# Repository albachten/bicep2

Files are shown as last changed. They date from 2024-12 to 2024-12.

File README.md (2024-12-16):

# Bicep2 - Flexing my "ARM" muscles

This is a simple ARM Cortex M0 development board with:
* SAMD21G18A cpu
* 0.96" OLED I2C display
* LiPo battery
* 2 I2C connectors (1 QWIIC and 1 header)
* 1 extra serial connector
* 1 rotary switch
* 4 pushbuttons
* 4 LEDs
* 1 neopixel LED
* 2 MB SPI flash

This is designed for prototyping.
I find that almost every time I'm trying new hardware I need some combination of LEDs, buttons, rotary switch, or an OLED display.
The display is connected to the I2C bus and can be disconnected by removing the jumper resistors.
The switches and LEDs can be connected to digital pins with jumper wires.

The SPI flash enables using the same bootloader as the adafruit feather m0 express.  This memory is typically used for CircuitPython but can also be used for general storage.

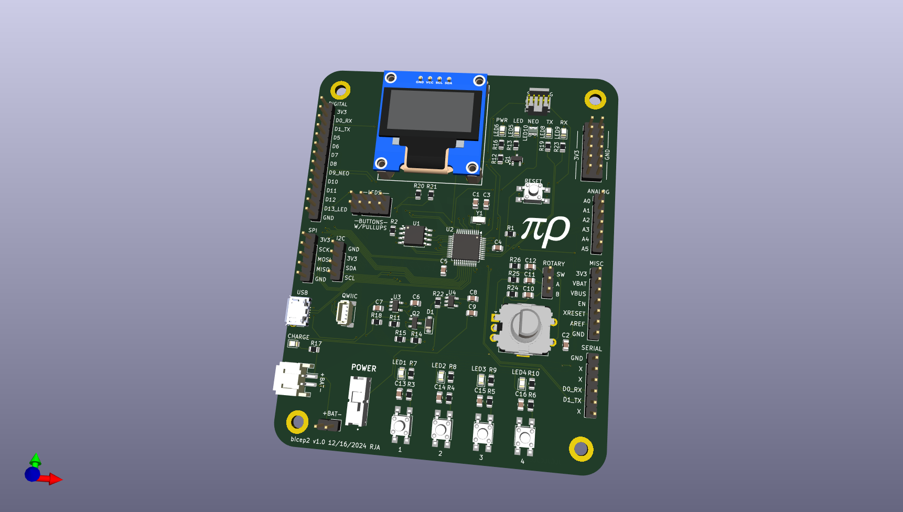
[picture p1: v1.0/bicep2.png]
PCB


Schematic

[Schematic pdf](v1.0/bicep2.pdf)

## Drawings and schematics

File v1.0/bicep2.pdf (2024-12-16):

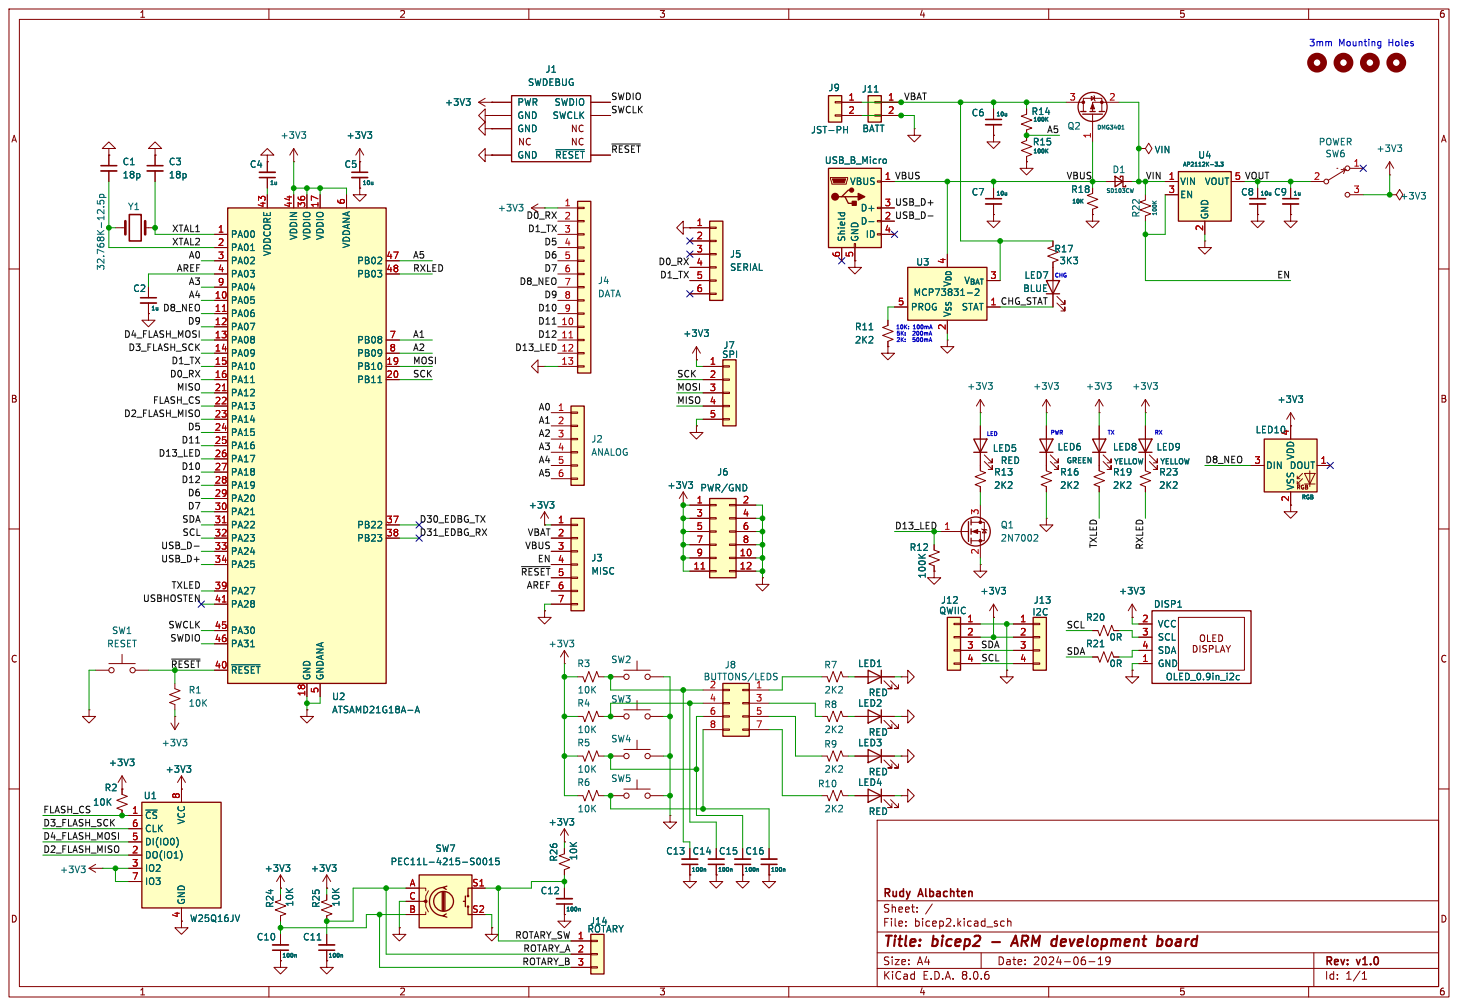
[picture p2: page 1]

File: bicep2.kicad_sch Sheet: / Rudy Albachten

Id: 1/1 Title: bicep2 - ARM development board

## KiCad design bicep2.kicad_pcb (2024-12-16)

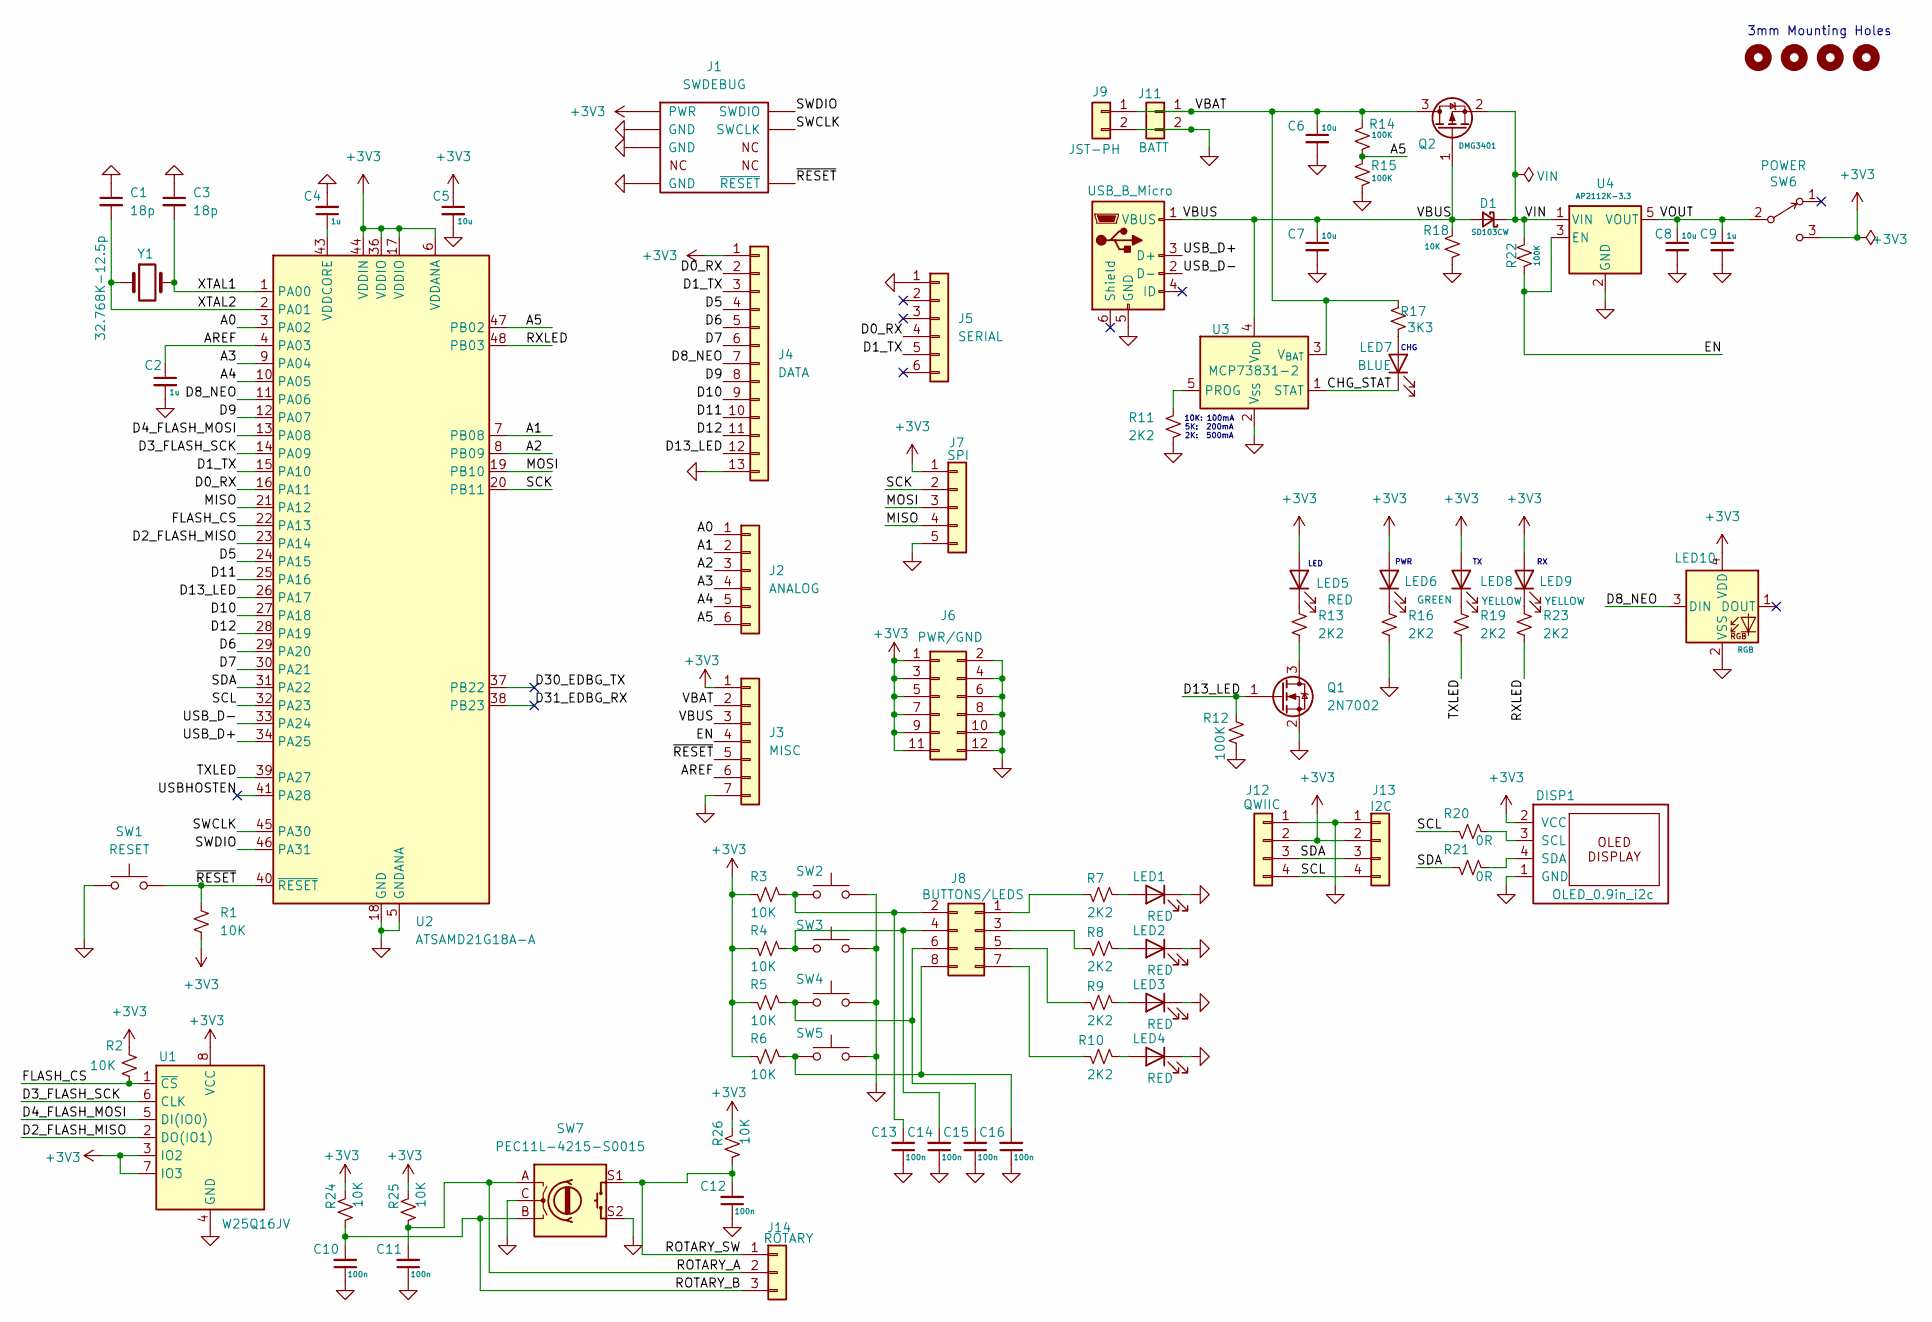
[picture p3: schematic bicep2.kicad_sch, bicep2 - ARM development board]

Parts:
C1, C3: 18p; C_0805_2012Metric
C2, C4, C9: 1u; C_0805_2012Metric
C5, C6, C7, C8: 10u; C_0805_2012Metric
C10, C11, C12, C13, C14, C15, C16: 100n; C_0805_2012Metric
D1: SD103CW; D_SOD-123
DISP1: OLED_0.9in_i2c; OLED_0.9in_i2c_weewooday
H1, H2, H3, H4: MountingHole_Pad; MountingHole_3.2mm_M3_ISO7380_Pad
J1: SWDEBUG; CortexDebug
J2: ANALOG; PinHeader_1x06_P2.54mm_Vertical
J3: MISC; PinHeader_1x07_P2.54mm_Vertical
J4: DATA; PinHeader_1x13_P2.54mm_Vertical
J5: SERIAL; PinHeader_1x06_P2.54mm_Vertical
J6: PWR/GND; PinHeader_2x06_P2.54mm_Vertical
J7: SPI; PinHeader_1x05_P2.54mm_Vertical
J8: BUTTONS/LEDS; PinHeader_2x04_P2.54mm_Vertical
J9: JST-PH; JST_PH_S2B-PH-SM4-TB_1x02-1MP_P2.00mm_Horizontal
J10: USB_B_Micro; USB_Micro-B_Amphenol_10118194_Horizontal
J11: BATT; PinHeader_1x02_P2.54mm_Vertical
J12: QWIIC; QWIIC_JST_SH_BM04B-SRSS-TB_1x04-1MP_P1.00mm_Vertical
J13: I2C; PinHeader_1x04_P2.54mm_Vertical
J14: ROTARY; PinHeader_1x03_P2.54mm_Vertical
LED1, LED2, LED3, LED4, LED5: RED; LED_0805_2012Metric
LED6: GREEN; LED_0805_2012Metric
LED7: BLUE; LED_0805_2012Metric
LED8, LED9: YELLOW; LED_0805_2012Metric
LED10: RGB; LED_WS2812B-2020_PLCC4_2.0x2.0mm
Q1: 2N7002; SOT-23
Q2: DMG3401; SOT-23
R1, R2, R3, R4, R5, R6, R18, R24, R25, R26: 10K; R_0805_2012Metric
R7, R8, R9, R10, R11, R13, R16, R19, R23: 2K2; R_0805_2012Metric
R12, R14, R15, R22: 100K; R_0805_2012Metric
R17: 3K3; R_0805_2012Metric
R20, R21: 0R; R_0805_2012Metric
SW1: RESET; TL3305B_SPST_PushButton
SW2, SW3, SW4, SW5: TL3305B; TL3305B_SPST_PushButton
SW6: POWER; EG1218_SPDT_Slide_Switch
SW7: PEC11L-4215-S0015; RotaryEncoder_Alps_EC11E-Switch_Vertical_H20mm
U1: W25Q16JV; SOIC-8_5.23x5.23mm_P1.27mm
U2: ATSAMD21G18A-A; TQFP-48_7x7mm_P0.5mm
U3: MCP73831-2; SOT-23-5
U4: AP2112K-3.3; SOT-23-5
Y1: 32.768K-12.5p; Crystal_SMD_G8-2Pin_3.2x1.5mm

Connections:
+3V3: C5.1, DISP1.2 (VCC), J1.1 (PWR), J3.1, J4.1, J6.1, J6.3, J6.5, J6.7, J6.9, J6.11, J7.1, J12.2, J13.2, LED5.2 (A), LED6.2 (A), LED8.2 (A), LED9.2 (A), LED10.4 (VDD), R1.2, R2.2, R3.1, R4.1, R5.1, R6.1, R24.2, R25.2, R26.2, SW6.3 (C), U1.3 (IO2), U1.7 (IO3), U1.8 (VCC), U2.6 (VDDANA), U2.17 (VDDIO), U2.36 (VDDIO), U2.44 (VDDIN)
/A0: J2.1, U2.3 (PA02)
/A1: J2.2, U2.7 (PB08)
/A2: J2.3, U2.8 (PB09)
/A3: J2.4, U2.9 (PA04)
/A4: J2.5, U2.10 (PA05)
/A5: J2.6, R14.1, R15.2, U2.47 (PB02)
/AREF: C2.1, J3.6, U2.4 (PA03)
/CHG_STAT: LED7.1 (K), U3.1 (STAT)
/D0_RX: J4.2, J5.4, U2.16 (PA11)
/D1_TX: J4.3, J5.5, U2.15 (PA10)
/D2_FLASH_MISO: U1.2 (DO(IO1)), U2.23 (PA14)
/D3_FLASH_SCK: U1.6 (CLK), U2.14 (PA09)
/D4_FLASH_MOSI: U1.5 (DI(IO0)), U2.13 (PA08)
/D5: J4.4, U2.24 (PA15)
/D6: J4.5, U2.29 (PA20)
/D7: J4.6, U2.30 (PA21)
/D8_NEO: J4.7, LED10.3 (DIN), U2.11 (PA06)
/D9: J4.8, U2.12 (PA07)
/D10: J4.9, U2.27 (PA18)
/D11: J4.10, U2.25 (PA16)
/D12: J4.11, U2.28 (PA19)
/D13_LED: J4.12, Q1.1 (G), R12.1, U2.26 (PA17)
/D30_EDBG_TX: U2.37 (PB22)
/D31_EDBG_RX: U2.38 (PB23)
/EN: J3.4, R22.1, U4.3 (EN)
/FLASH_CS: R2.1, U1.1 (~CS), U2.22 (PA13)
/MISO: J7.4, U2.21 (PA12)
/MOSI: J7.3, U2.19 (PB10)
/ROTARY_A: C11.2, J14.2, R25.1, SW7.A
/ROTARY_B: C10.2, J14.3, R24.1, SW7.B
/ROTARY_SW: C12.2, J14.1, R26.1, SW7.S1
/RXLED: R23.2, U2.48 (PB03)
/SCK: J7.2, U2.20 (PB11)
/SCL: J12.4, J13.4, R20.1, U2.32 (PA23)
/SDA: J12.3, J13.3, R21.1, U2.31 (PA22)
/SWCLK: J1.4 (SWCLK), U2.45 (PA30)
/SWDIO: J1.2 (SWDIO), U2.46 (PA31)
/TXLED: R19.2, U2.39 (PA27)
/USBHOSTEN: U2.41 (PA28)
/USB_D+: J10.3 (D+), U2.34 (PA25)
/USB_D-: J10.2 (D-), U2.33 (PA24)
/VBAT: C6.1, J3.2, J9.1, J11.1, Q2.3 (D), R14.2, R17.1, U3.3 (V_{BAT})
/VBUS: C7.1, D1.2 (A), J3.3, J10.1 (VBUS), Q2.1 (G), R18.2, U3.4 (V_{DD})
/VIN: D1.1 (K), Q2.2 (S), R22.2, U4.1 (VIN)
/VOUT: C8.1, C9.1, SW6.2 (B), U4.5 (VOUT)
/XTAL1: C3.2, U2.1 (PA00), Y1.2
/XTAL2: C1.2, U2.2 (PA01), Y1.1
/~RESET: J1.10 (~RESET), J3.5, R1.1, SW1.2, U2.40 (~RESET)
GND: C1.1, C2.2, C3.1, C4.2, C5.2, C6.2, C7.2, C8.2, C9.2, C10.1, C11.1, C12.1, C13.1, C14.1, C15.1, C16.1, DISP1.1 (GND), J1.3 (GND), J1.5 (GND), J1.9 (GND), J3.7, J4.13, J5.1, J6.2, J6.4, J6.6, J6.8, J6.10, J6.12, J7.5, J9.2, J10.5 (GND), J11.2, J12.1, J13.1, LED1.1 (K), LED2.1 (K), LED3.1 (K), LED4.1 (K), LED10.2 (VSS), Q1.2 (S), R11.2, R12.2, R15.1, R16.2, R18.1, SW1.1, SW2.1, SW3.1, SW4.1, SW5.1, SW7.C, SW7.S2, U1.4 (GND), U2.5 (GNDANA), U2.18 (GND), U2.35 (GND), U2.42 (GND), U3.2 (V_{SS}), U4.2 (GND)
unnamed: DISP1.3 (SCL), R20.2
unnamed: DISP1.4 (SDA), R21.2
unnamed: J8.1, R7.1
unnamed: C13.2, J8.2, R3.2, SW2.2
unnamed: J8.3, R8.1
unnamed: C14.2, J8.4, R4.2, SW3.2
unnamed: J8.5, R9.1
unnamed: C15.2, J8.6, R5.2, SW4.2
unnamed: J8.7, R10.1
unnamed: C16.2, J8.8, R6.2, SW5.2
unnamed: LED1.2 (A), R7.2
unnamed: LED2.2 (A), R8.2
unnamed: LED3.2 (A), R9.2
unnamed: LED4.2 (A), R10.2
unnamed: LED5.1 (K), R13.1
unnamed: LED6.1 (K), R16.1
unnamed: LED7.2 (A), R17.2
unnamed: LED8.1 (K), R19.1
unnamed: LED9.1 (K), R23.1
unnamed: Q1.3 (D), R13.2
unnamed: C4.1, U2.43 (VDDCORE)
unnamed: R11.1, U3.5 (PROG)

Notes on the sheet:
PWR
3mm Mounting Holes
10K: 100mA 5K: 200mA 2K: 500mA
LED
CHG

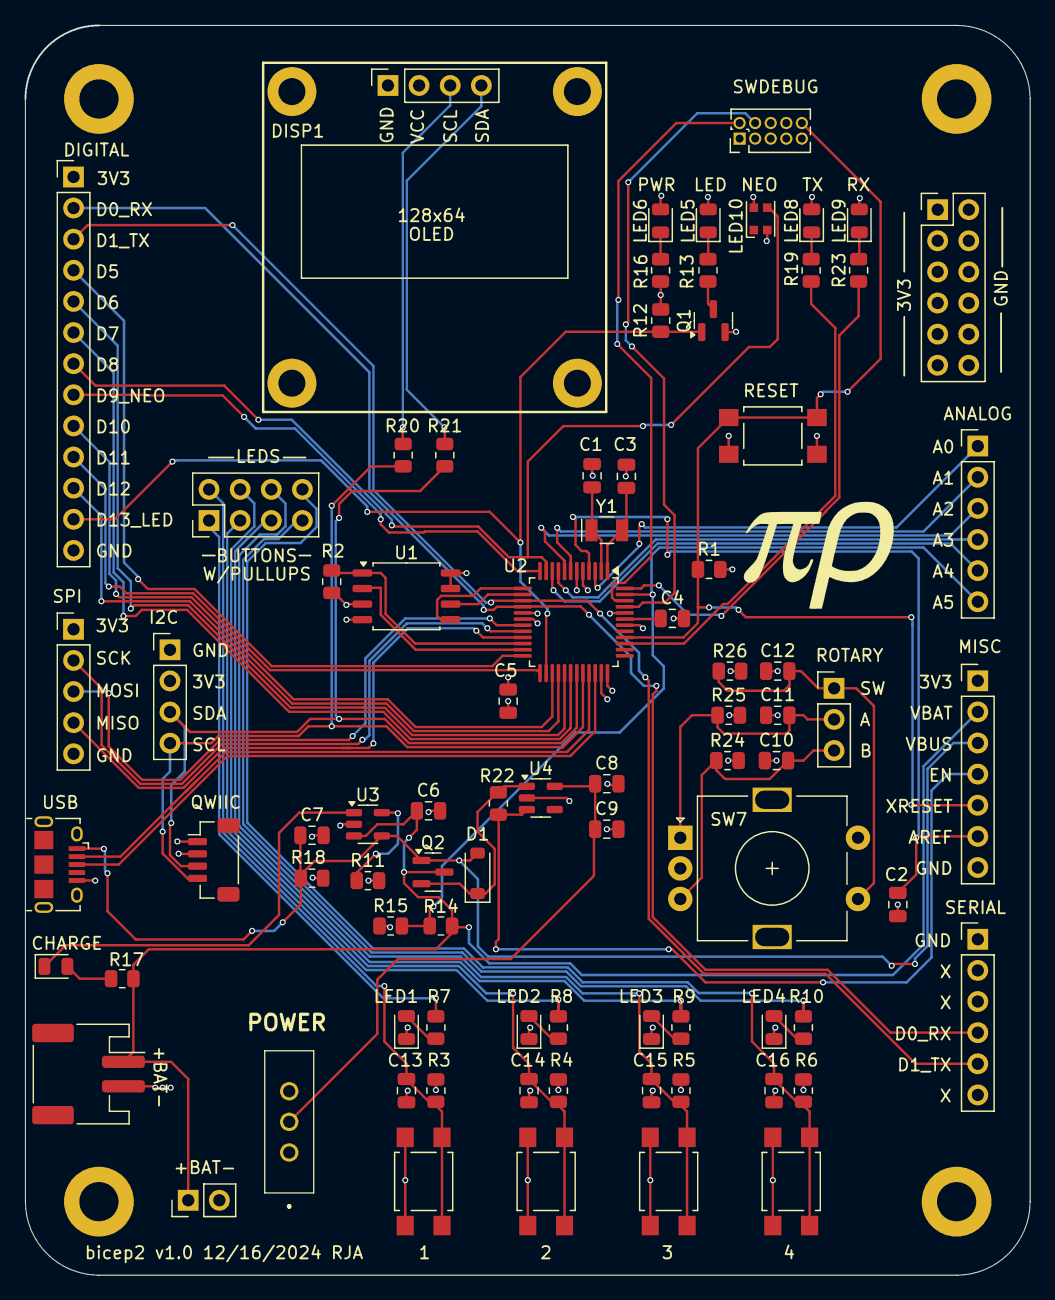
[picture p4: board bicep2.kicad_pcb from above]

Board: 4 copper layers, 82.0 x 102.0 mm, 88 parts (1 on the bottom side), 69 nets.

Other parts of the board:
G1: LOGO; pirho_0.50
G2: LOGO; pirho
